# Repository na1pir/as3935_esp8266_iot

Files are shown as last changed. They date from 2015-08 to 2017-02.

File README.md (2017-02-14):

# Thunderstorm sensor protected iot switch
*Another a bit more complex project written in c with espressif sdk for my diploma thesis, so it is in prototype stage and work in progress when I have time to work on it . . .*

Copyright (c) 2015 Uroš Golob <golob.uros@gmail.com> 
 
Work was done with intention to protect electronic devices and so lower e-waste.
It might work or it may not, just don't sue me if your house burns down or if it kills you...

This software and hardware is described in my diploma thesis(work in progress). 
   
Use it for *personal* use as you wish, just keep this notice on it if you do! 
And return changes back free of charge by same restrictions and notice! 

This software uses espressif sdk software, spi library from David Ogilvy(MetalPhreak) and libesphttpd & wifi settins form Jeroen Domburg(sprite_fm). So use and rescpect their respective licencies for their work. 

Development took alot of time and money so remember me with some spare 
bitcoins: 1MaGphnuiMjywjQPKHKF239wzcef4KpNxX if you wish:)

For comercial use you can contact me and we can make some separate licencing deal...

## What it is?
Well this thing uses some crazy trickery from ams... and lovely soc from espressif... 
OK as3935 is (well not so simple) chip that uses LC antenna tuned to 500khz to detect lightning discharges.
It measures amplitude and uses some crazy statistics to determine distance from face of the thunderstorm. And gladly ignores man made discharges.
Well I added a bit of trickery of my own to libesphttpd and used spi driver to talk to as3935 with esp8266.
When you mix everything together add couple of passives, transistor, optotransistor and relays you got a switch that disengages relay when it detect nearby thunderstorm. 

This is my baby and so work in progress and maybe never ending rolling release... 

Well you can order boards from [DirtyPCB's] 
(http://dirtypcbs.com/view.php?share=10417&accesskey=882ad84b962361d538d1656b4bbab783)

## bom: 
 * esp-201 or esp12 or esp12e
 * as3935
 * ma5532
 * ams1117 3.3
 * optotransistors
 * npns
 * couple of R, C & D 
 * pair of relays

## how to:
1. get yourself working esp-open-sdk + newer sdk from espressif and link it to esp-open-sdk/sdk 
2. additionally get working sprite_fm libesphttpd and cats/led example so you can check and update any changes... 
3. find spi driver from MetalPhreak and check that example

 * I should add everything as git sub-modules, but as of now I don't know how...

 * make sure to export your esp-open-sdk/xtensa-lx106-elf/bin path to system path... additionally export esp-open-sdk/sdk as SDK_BASE, then ESPTOOL... in ubuntu it is best to do it in .profile  

4. from as3935_esp8266_iot folder run

	**make clean all**

5. put esp into boot mode (i have reset and boot(rst and gpio0 respectively to gnd) buttons soldered into my board) so press reset and boot then lift reset first then boot and run

	**make burn** 
or 
	**sudo make burn** 
if your dial-out permission thingy stuffs aren't setup properly

6. for debbuging

	**make tty**

7. setup geany for above commands it will save you lots of time

*todo: fix all issues*

## user interface looks like this: 
![settings web page]
(https://github.com/na1pir/as3935_esp8266_iot/raw/master/webpage.png)

Text for thesis is available at https://dk.um.si/Dokument.php?id=99783&lang=eng
It is in Slovene language but generaly you can still look at pictures.

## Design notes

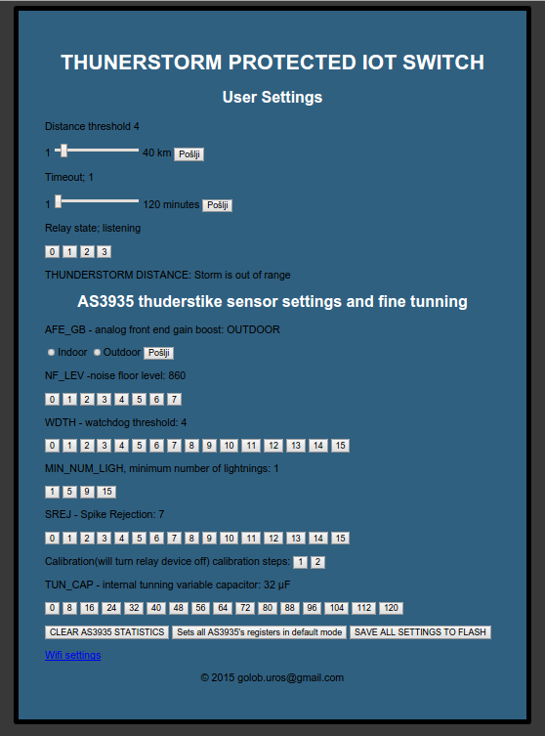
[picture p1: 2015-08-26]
webpage.png

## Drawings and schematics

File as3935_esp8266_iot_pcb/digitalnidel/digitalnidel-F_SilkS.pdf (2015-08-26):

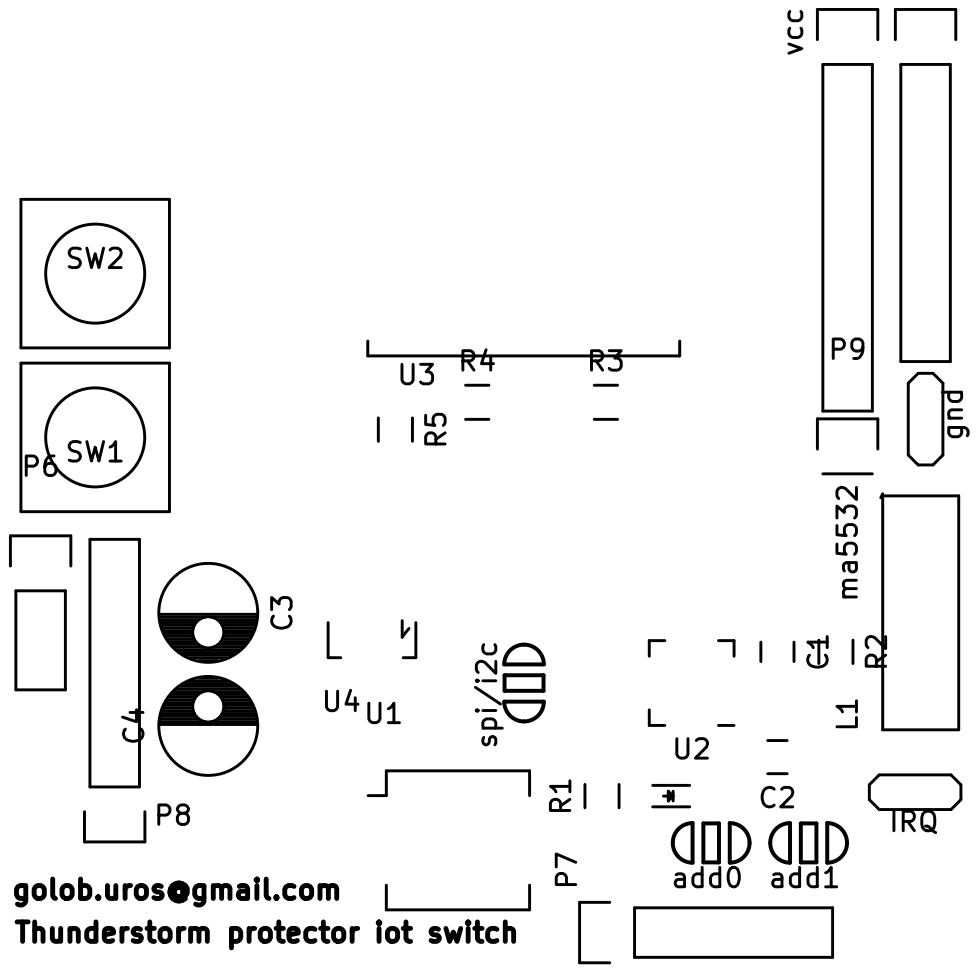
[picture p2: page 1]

Thunderstorm protector iot switch

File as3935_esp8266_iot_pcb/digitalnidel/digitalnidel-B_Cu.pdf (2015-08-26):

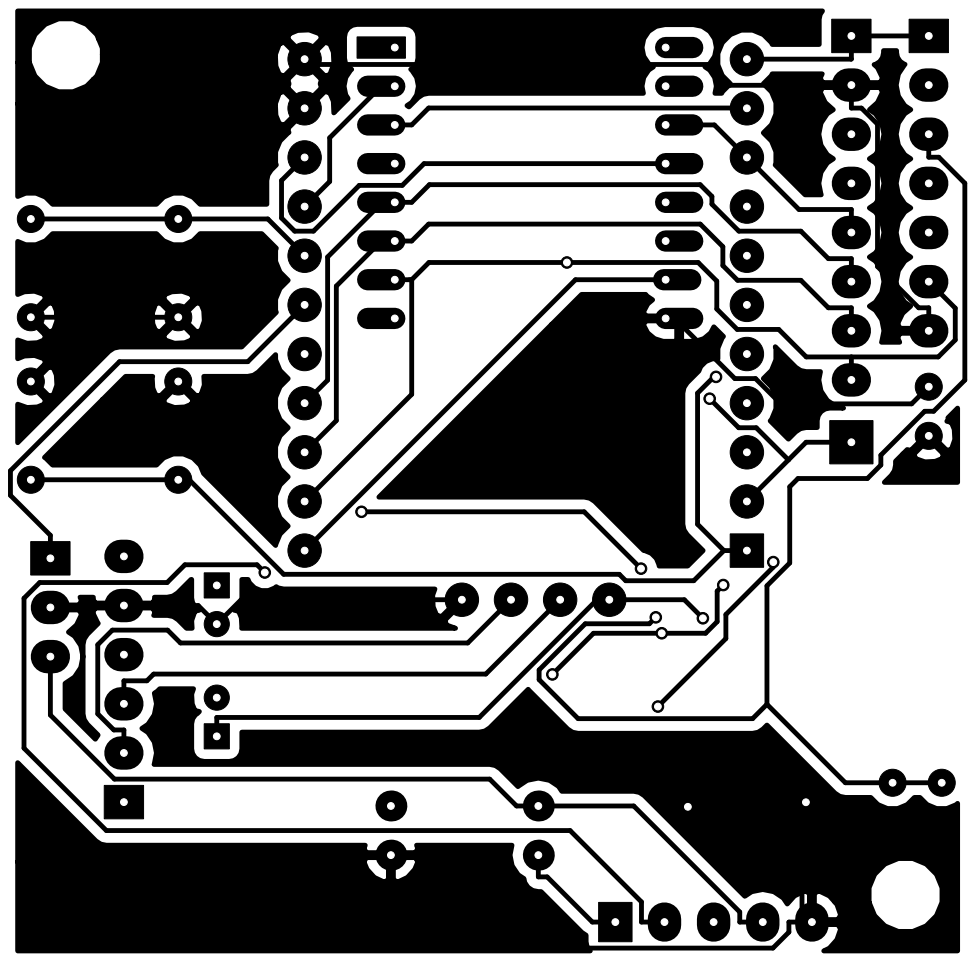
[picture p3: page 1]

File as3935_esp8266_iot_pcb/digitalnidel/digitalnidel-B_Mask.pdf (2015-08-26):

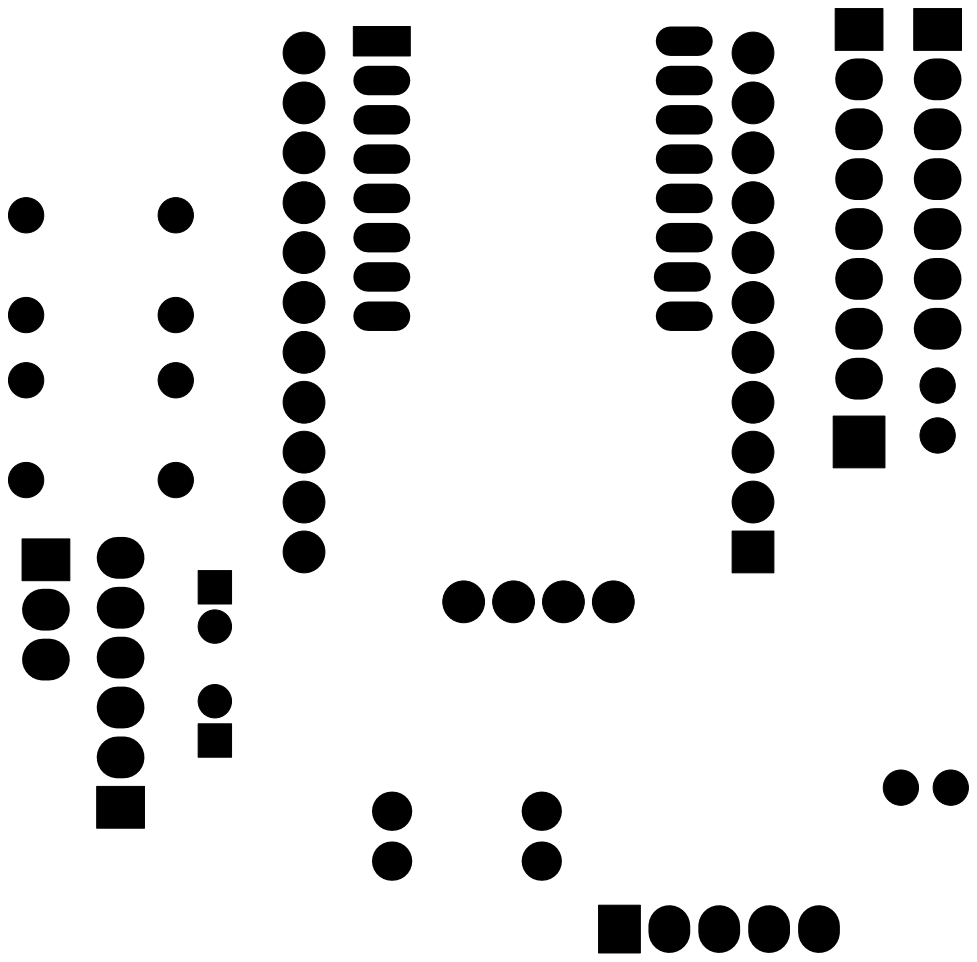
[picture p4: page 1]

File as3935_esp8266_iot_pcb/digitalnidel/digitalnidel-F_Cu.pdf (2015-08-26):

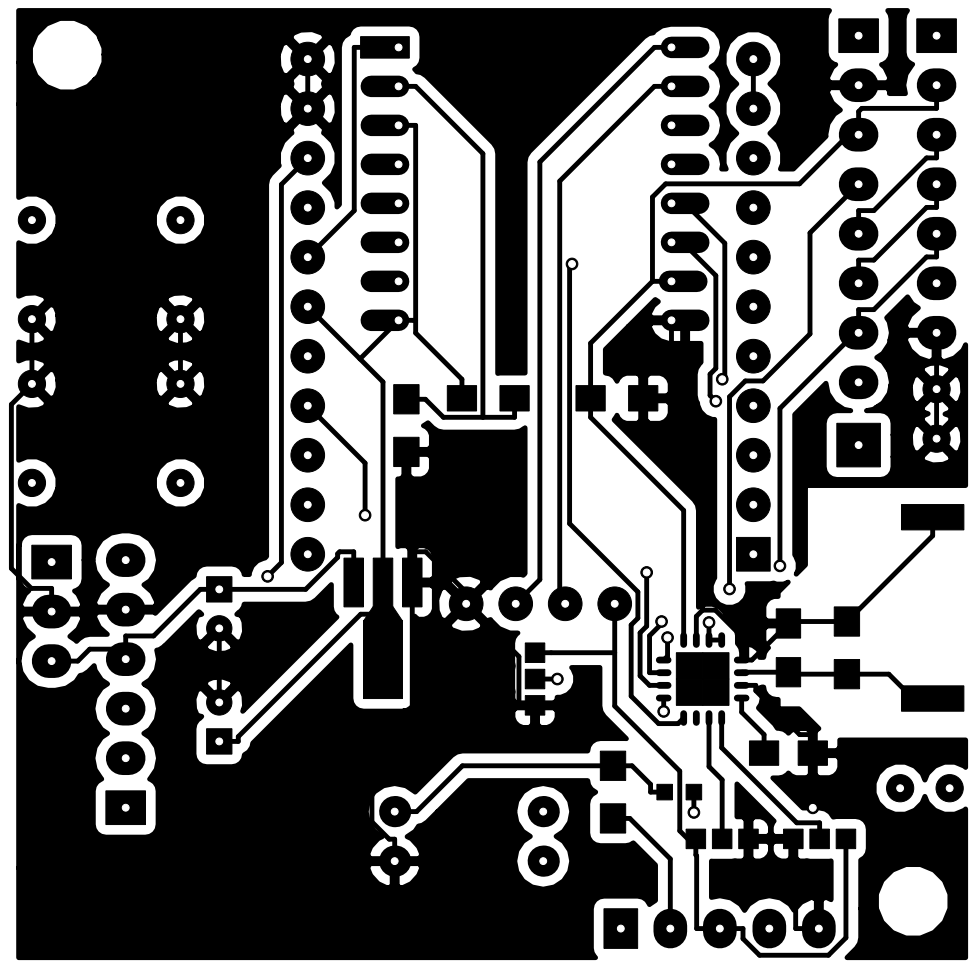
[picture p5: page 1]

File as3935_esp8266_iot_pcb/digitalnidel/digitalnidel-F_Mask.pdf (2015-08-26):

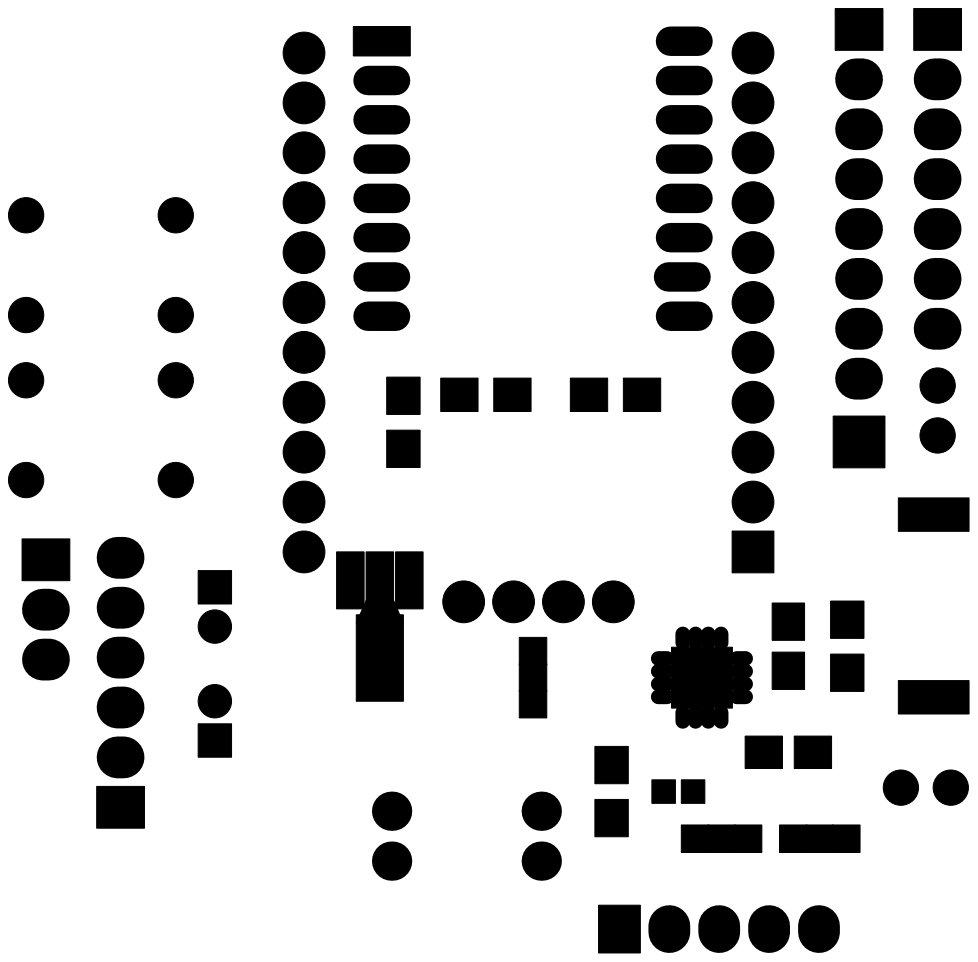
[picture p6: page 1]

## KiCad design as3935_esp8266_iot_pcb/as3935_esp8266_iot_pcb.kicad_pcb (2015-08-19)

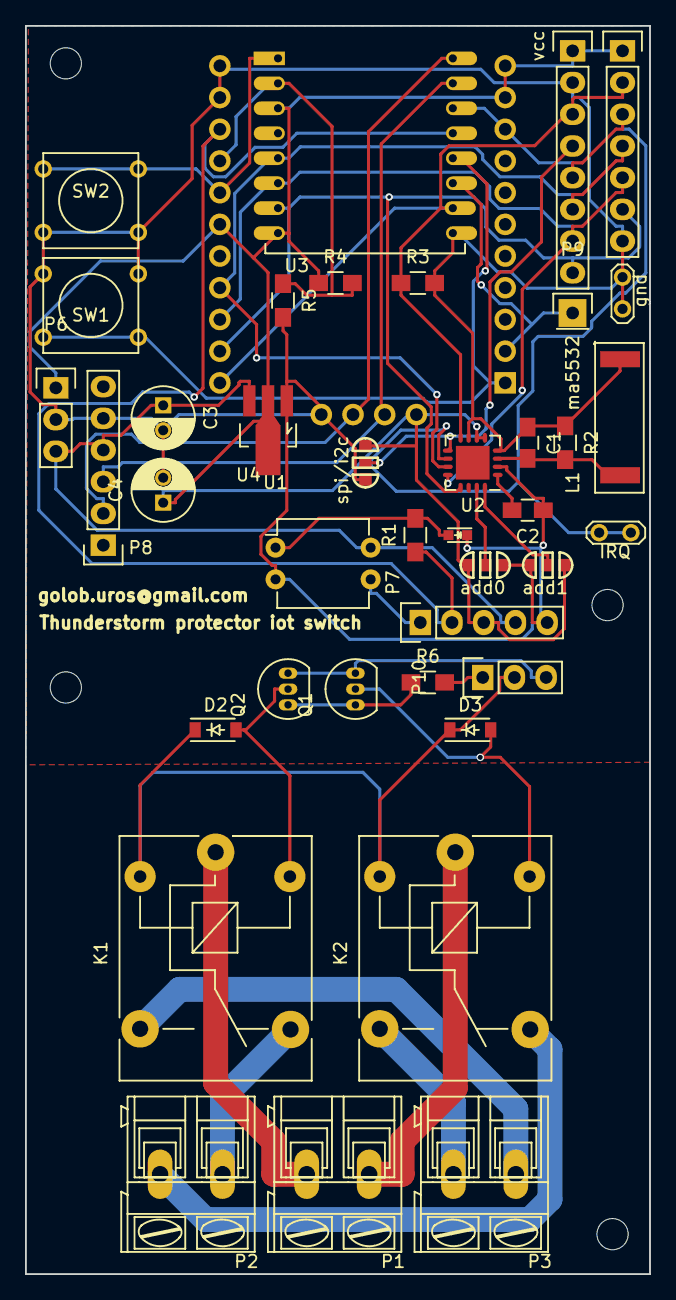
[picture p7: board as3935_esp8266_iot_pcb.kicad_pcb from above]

Board: 2 copper layers, 50.0 x 100.0 mm, 44 parts (0 on the bottom side), 31 nets.

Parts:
C1, C2: C; C_0805_HandSoldering
C3, C4: C; C_Radial_D5_L11_P2
D1: LED; LED-0603
D2, D3: D; SOD-123
IRQ: TEST; TESTPOINT
K1, K2: RELAY_2RT; relay
L1: ma5532
P1, P2, P3: CONN_01X02; AK300-2
P5: CONN_01X07; Pin_Header_Straight_1x07
P6, P10: CONN_01X03; Pin_Header_Straight_1x03
P7: CONN_01X05; Pin_Header_Straight_1x05
P8: CONN_01X06; Pin_Header_Straight_1x06
P9: CONN_01X01; Pin_Header_Straight_1x01
Q1, Q2: Q_NPN_BCE; TO-92_Inline_Narrow_Oval
R1, R2, R3, R4, R5, R6: R; R_0805_HandSoldering
REF1, REF2, REF3, REF4: MountingHole_2-5mm
SW1: SW_FLASH; SW_PUSH_SMALL
SW2: SW_RESET; SW_PUSH_SMALL
U1: PC817; DIP-4_W7.62mm
U2: as3935; UQFN-16-1EP_4x4mm_Pitch0.65mm
U3: ESP-12
U4: ESP-201
U5: AP1117D33; SOT89-3_Housing_Handsoldering
add0, add1: JUMPER3; sj3
gnd: TEST; TESTPOINT
spi/i2c: JUMPER3; sj3
vcc: CONN_01X08; Pin_Header_Straight_1x08

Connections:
+3V3: C4.1, P5.1, P6.1, P7.3, R4.1, U2.5, U2.6, U3.3, U3.8, U4.10, U4.11, U4.17, U4.26, U5.2, add0.1, add1.1, spi/i2c.1, vcc.1
+5V: C3.1, D2.1, D3.1, K1.8, K2.8, P6.3, P7.4, P8.4, P10.2, U1.4, U5.3
/adc: R4.2, R5.1, U3.2, U4.15
/add0: U2.15, add0.2
/add1: U2.16, add1.2
/clk: P5.4, U2.11, U3.5, U4.19, vcc.6
/cs: P5.2, R3.1, U2.8, U3.10, U4.22, vcc.3
/flash: SW1.1, U3.12, U4.1
/irq: IRQ.1, P5.3, U2.10, U3.14, U4.9, vcc.5
/miso: P5.5, U2.12, U3.6, U4.20, vcc.7
/mosi: P5.6, U2.13, U3.7, U4.21, vcc.8
/reset: SW2.1, U3.1, U4.16
/rx: P8.3, U3.15, U4.25
/si: U2.9, spi/i2c.2, vcc.4
/to_sw: P7.2, R1.1, U3.13, U4.14
/to_switch: P7.1, P10.1, R6.2, U1.3
/tx: P8.2, U3.16, U4.24
GND: C1.1, C2.1, C3.2, C4.2, D1.1, L1.1, P5.7, P6.2, P7.5, P8.5, P10.3, Q1.3, Q2.3, R2.1, R3.2, R5.2, SW1.2, SW2.2, U1.2, U2.2, U2.4, U2.7, U3.9, U4.12, U4.13, U4.23, U5.1, add0.3, add1.3, gnd.1, spi/i2c.3, vcc.2
unnamed: C1.2, L1.2, R2.2, U2.3
unnamed: C2.2, U2.1
unnamed: D1.2, R1.2, U1.1
unnamed: D2.2, K1.9, Q2.2
unnamed: D3.2, K2.9, Q1.2
unnamed: K1.1, P2.1
unnamed: K1.3, P3.1
unnamed: K1.5, P1.2
unnamed: K2.1, P2.2
unnamed: K2.3, P3.2
unnamed: K2.5, P1.1
unnamed: P9.1, U3.11, U4.2
unnamed: Q1.1, Q2.1, R6.1

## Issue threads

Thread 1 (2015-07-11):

TUN_CAP and WDTH

na1pir, 2015-07-11:
only even web gui buttons for adjusting cunning capacitors work.

na1pir, 2015-07-13:
Using different debug printouts I fined out that correct values get from esp8266 webpage to where we write that into as3935. So process of writing that into chip or read back is real issue.

na1pir, 2015-07-26:
same problem applies to WDTH as well

na1pir, 2015-08-11:
WRITE_PERI_REG(SPI_CTRL2(HSPI), 2<<SPI_MOSI_DELAY_MODE_S);
fixed wrong writing to chip so read-back became correct as well.
might need some additional testing thou ...

Closed 2015-08-11.

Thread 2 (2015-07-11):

lco calibration

na1pir, 2015-07-11:
lco calibration doesn't work there must be something wrong with spi protocol or maybe with delays.

na1pir, 2015-07-13:
fixed by adding additional reserved bit into as3935 structure

Closed 2015-07-13.

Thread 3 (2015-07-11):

interrupts won't fire

na1pir, 2015-07-11:
probably something wrong with gpio settings

na1pir, 2015-08-11:
currently just reading irq pin in procTask and functionality is almost as same as interrupts...

na1pir, 2016-03-20:
issue was hardware based

Closed 2016-03-20.

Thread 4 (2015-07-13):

interrupt noise and disturber log  on webpage

na1pir, 2015-07-13:
it would be nice if we would have printout for disturbers and noise level to high interrupts
and settings to disable disturbers

na1pir, 2015-08-11:
maybe current interrupt value would be good enough.

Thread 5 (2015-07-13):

saving settings to flash

na1pir, 2015-07-13:
it would be nice if we could save settings to flash;
-1 default settings button
-couple different profiles for different settings so if we use device in multiple locations.
-loading last used settings on boot

na1pir, 2015-07-30:
implemented partially - I guess all that we actually need:
- 1 save button for saving all settings
- loading that setting on boot time

Closed 2015-07-30.

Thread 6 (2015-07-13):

currently relay does not switch in listening mode

na1pir, 2015-07-13:
This is probably because of interrupts won't fire, so we are not switching between stages like software design intended (to switch between stages). So when we fix interrupts all should be well.
I should recheck all stages an maybe add intermediate stages better called pending.

na1pir, 2015-07-26:
after some tweaking we can do without interrupts only by pulling data from registers, but our response time is fixed to 1-2 seconds

Closed 2015-07-26.

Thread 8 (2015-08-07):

visual feedback - blinkenlights

na1pir, 2015-08-07:
you could add some sort of visual feedback for certain danger level and device state in form of blinkenlights :)

na1pir, 2015-08-12:
https://github.com/cnlohr/esp8266ws2812i2s would make sense for this, but then we lose uart line for debugging.

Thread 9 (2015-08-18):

auto update webpage for changes

na1pir, 2015-08-18:
you could use websockets for updating distance, last interrupts, current register values,...

na1pir, 2015-08-18:
you could even stream debug data instead of using uart

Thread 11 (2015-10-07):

pcb error

na1pir, 2015-10-07:
esp8266 can't drive inductive load directly, nor can it drive specified opto-transistor

na1pir, 2015-10-18:
well I guess fake esp12e modules are responsible for this one, because they mistakenly switched gpio5 and gpio4

na1pir, 2016-01-02:
not certain if I should change that since all boards I have save gpio 4 and 5 switched in respect to this pcb.

na1pir, 2016-03-20:
this is couse of #3

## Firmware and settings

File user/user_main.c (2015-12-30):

/*
 * Copyright (C) 2015 Uroš Golob <golob.uros@gmail.com>
 * 
 * Work was done with intention to protect electronic devices and so lower e-waste.
 * It might work or it may not, just don't sue me if your house burns down or if it kills you...
 * 
 * This software and hardware is described in my diploma thesis(work in progress). 
 *   
 * Use it for personal use as you wish, just keep this notice on it if you do! 
 * And return changes back free of charge by same restrictions and this notice! 
 * 
 * For comercial use you can contact me and we can make apropriate licencing deal...
 *
 * Development took alot of time and money so remember me with some spare 
 * bitcoins: 1MaGphnuiMjywjQPKHKF239wzcef4KpNxX if you wish:)
 * 
 * This software uses espressif sdk software, spi library from David Ogilvy(MetalPhreak) and libesphttpd & wifi settins from Jeroen Domburg(sprite_fm). So use and rescpect their respective licencies for their work. 
 */
 #include <stdint.h>
#include <esp8266.h>
#include "httpd.h"
#include "httpdespfs.h"
#include "cgi.h"
#include "cgiwifi.h"
#include "cgiflash.h"
#include "stdout.h"
#include "espfs.h"
#include "captdns.h"
#include "webpages-espfs.h"

#include "ets_sys.h"
#include "osapi.h"
#include "gpio.h"
#include "os_type.h"
#include "user_config.h"
#include "uart.h"
#include "uart_register.h"
#include "user_interface.h"
#include "ip_addr.h"
#include "espconn.h"
#include "as3935.h"
#include "spi_flash.h"
#include "mem.h"
#include "espconn.h"
#include "driver/spi.h"
#include "driver/spi_register.h"

uint32_t i;


volatile uint32_t in_detection_counter=0;

volatile uint8_t tick_flag = 1;
volatile uint8_t interrupt_flag=0;
volatile uint8_t interrupt_set=0;
volatile uint8_t tock=1;


void user_rf_pre_init(void){
	//just becouse we have to http://bbs.espressif.com/viewtopic.php?t=486&p=1895
//initialize things that should be done before rf connection - nothing actualy
}

//0 off
//1 on
//2 calibration
//3 listening
//4 in detection treshold > distance //relay on
//5 in detection treshold > distance timeout //relay off we are out of danger but timeout is still pending 
//6 in detection treshold < distance //off

volatile uint8_t state_machine=0;

 uint8_t threshold_distance=30;
 uint8_t threshold_timeout=15;

 uint8_t tuncaplookuptable[]={ 0,8,16,24,32,40 ,48 ,56 ,64 ,72,80,88,96,104,112,120};
 uint16_t noise_outdoor[]={390, 630, 860, 1100, 1140, 1570, 1800, 2000};
 uint16_t noise_indoor[]={28, 45, 62, 78, 95, 112, 130, 146};
 uint8_t min_num_ligh[]={1,5,9,15};
 uint8_t lcofdiv[]={16,32,64,128};


HttpdBuiltInUrl builtInUrls[]={
	{"/", cgiRedirect, "/index.tpl"},
	{"/index.tpl", cgiEspFsTemplate, tplas3935},
	{"/as3935.cgi", cgias3935, NULL},

	//Routines to make the /wifi URL and everything beneath it work.

	{"/wifi", cgiRedirect, "/wifi/wifi.tpl"},
	{"/wifi/", cgiRedirect, "/wifi/wifi.tpl"},
	{"/wifi/wifiscan.cgi", cgiWiFiScan, NULL},
	{"/wifi/wifi.tpl", cgiEspFsTemplate, tplWlan},
	{"/wifi/connect.cgi", cgiWiFiConnect, NULL},
	{"/wifi/connstatus.cgi", cgiWiFiConnStatus, NULL},
	{"/wifi/setmode.cgi", cgiWiFiSetMode, NULL},

	{"*", cgiEspFsHook, NULL}, //Catch-all cgi function for the filesystem
	{NULL, NULL, NULL}
};

uint64_t seconds_from_boot=0;

void ICACHE_FLASH_ATTR ticker_timer(void *arg)
{
	tick_flag=1;
	if(state_machine>4){//2
		in_detection_counter++;//this is reseted in solid state machine 6
	}
	seconds_from_boot++;
	//if(seconds_from_boot%15==0){
		os_printf("Heap: %ld\nAFE_GB[%d],NF_LEV[%d],WDTH[%d],MIN_NUM_LIGH[%d],SREJ[%d],INT[%d],LCO_FDIV[%d],MASK_DIST[%d],DISTANCE[%d],TUN_CAP[%d], STATE[%d]\n",(unsigned long)system_get_free_heap_size(),as3935.x0.a0.AFE_GB,as3935.x1.a1.NF_LEV,as3935.x1.a1.WDTH,as3935.x2.a2.MIN_NUM_LIGH,as3935.x2.a2.SREJ,as3935.x3.a3.INT,as3935.x3.a3.LCO_FDIV,as3935.x3.a3.MASK_DIST,as3935.x7.a7.DISTANCE,as3935.x8.a8.TUN_CAP,state_machine);
	//}
}



#define procTaskPrio        0
#define procTaskQueueLen    1

os_timer_t some_timer;
os_event_t    procTaskQueue[procTaskQueueLen];

//0 off
//1 on
//2 calibration
//3 listening
//4 in detection treshold > distance //relay on
//5 in detection treshold > distance timeout //relay off we are out of danger but timeout is still pending 
//6 in detection treshold < distance //off
static void ICACHE_FLASH_ATTR procTask(os_event_t *events)
{

	//reschedule
	system_os_post(procTaskPrio, 0, 0 );
	
	
	if(tick_flag==1){
		//todo if interrups start to work anytime soon you only read periodicly when in detection 
		if(tock==1){
			if(state_machine>2){
				as3935_chip_read();
			}
			tock=0;
		}
		else{//alternative to interrupts
		if(GPIO_INPUT_GET(GPIO_ID_PIN(INT_PIN))){//instead of interrupt just read
			pending_interrupt();
		}
			tock=1;
			if(state_machine>2){
				if(as3935.x7.a7.DISTANCE<threshold_distance){
					uart0_sendStr("atention:\n");
					state_machine=6;
				}
			}
				
		}

		tick_flag=0;
		if(interrupt_flag){
			clear_interrupt();
			interrupt_flag=0;
			//return;
		}
		
		if(state_machine==6){
			if(!interrupt_set){
				setup_interrupt();
			}
			as3935_get_lightning_distance();
			if(as3935.x7.a7.DISTANCE<threshold_distance){
				GPIO_OUTPUT_SET(GPIO_ID_PIN(RELAY_PIN),0);//off
				in_detection_counter=0; //reset counter
				uart0_sendStr("danger\n");
				//return;
			}else {
				state_machine=5;
				//return;
			}
		}
		
		if(state_machine==5){
			if(!interrupt_set){
				setup_interrupt();
			}
			if(in_detection_counter>threshold_timeout*60){
					state_machine=4;	
			}
			uart0_sendStr("awaiting timeout\n");
			//return;
		}
		
		if(state_machine==4){
			if(!interrupt_set){
				setup_interrupt();
			}
			GPIO_OUTPUT_SET(GPIO_ID_PIN(RELAY_PIN),1);	
			if(as3935.x7.a7.DISTANCE==63){
				state_machine=3;
				
				uart0_sendStr("thunderstorm passed\n");
				//return;
			}
		}

		if(state_machine==1){
			as3935_disable_LCO_calibration_mode();
			disable_interrupt();
			uart0_sendStr("on\n");
			GPIO_OUTPUT_SET(GPIO_ID_PIN(RELAY_PIN),1);	
		}
		
		if(state_machine==2){
			if(interrupt_set){
				disable_interrupt();
			}
			GPIO_OUTPUT_SET(GPIO_ID_PIN(RELAY_PIN),0);	
			uart0_sendStr("lco cal\n");
			as3935_enable_LCO_calibration_mode();
		}
		
		if(state_machine==0){
			as3935_disable_LCO_calibration_mode();
			if(interrupt_set){
				disable_interrupt();
			}
			uart0_sendStr("off\n");
			GPIO_OUTPUT_SET(GPIO_ID_PIN(RELAY_PIN),0);	
			//uart0_sendStr("off\n");
		}
		
		if(state_machine==3){
			as3935_disable_LCO_calibration_mode();
			if(!interrupt_set){
				setup_interrupt();
			}
			GPIO_OUTPUT_SET(GPIO_ID_PIN(RELAY_PIN),1);	
			uart0_sendStr("thunderstrike protection\n");
		}
	}//tok
}




#define SSID "wlan"
#define SSID_PASSWORD "password"


void user_init(void) {
	
	char ssid[32] = SSID;
    char password[64] = SSID_PASSWORD;
    struct station_config station_conf;
    
    //Set station mode (connecting to another network great for testing)
    //wifi_set_opmode( 0x1 );
    
    //or lets just make our own - for offline
   // wifi_set_opmode( 0x2 );
    
    //station+softap 
	wifi_set_opmode( 0x3 ); //warning power hungry

    //Set ap settings
    os_memcpy(&station_conf.ssid, ssid, 32);
    os_memcpy(&station_conf.password, password, 64);
    wifi_station_set_config(&station_conf);
	
	stdoutInit();

	//initialize chip
	as3935_init();
	
	//enable "clock" couter
	system_os_task(procTask, procTaskPrio, procTaskQueue, procTaskQueueLen);
	os_timer_disarm(&some_timer);
	os_timer_setfn(&some_timer, (os_timer_func_t *)ticker_timer, NULL);
	os_timer_arm(&some_timer, 1000, 1); 
	
	//sqedule worker task
	system_os_post(procTaskPrio, 0, 0 );

	// 0x40200000 is the base address for spi fash memory mapping, ESPFS_POS is the position
	// where image is written in flash that is defined in Makefile.
#ifdef ESPFS_POS
	espFsInit((void*)(0x40200000 + ESPFS_POS));
#else
	espFsInit((void*)(webpages_espfs_start));
#endif
	httpdInit(builtInUrls, 80);
	
	load_setings();

	os_printf("\nInit done!\n");
}

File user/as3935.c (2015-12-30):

/*
 * Copyright (C) 2015 Uroš Golob <golob.uros@gmail.com>
 * 
 * Work was done with intention to protect electronic devices and so lower e-waste.
 * It might work or it may not, just don't sue me if your house burns down or if it kills you...
 * 
 * This software and hardware is described in my diploma thesis(work in progress). 
 *   
 * Use it for personal use as you wish, just keep this notice on it if you do! 
 * And return changes back free of charge by same restrictions and this notice! 
 * 
 * For comercial use you can contact me and we can make apropriate licencing deal...
 *
 * Development took alot of time and money so remember me with some spare 
 * bitcoins: 1MaGphnuiMjywjQPKHKF239wzcef4KpNxX if you wish:)
 * 
 * This software uses espressif sdk software, spi library from David Ogilvy(MetalPhreak) and libesphttpd & wifi settins from Jeroen Domburg(sprite_fm). So use and rescpect their respective licencies for their work. 
 */

#include "as3935.h"

struct as3935_t as3935;

void pending_interrupt(){
	uart0_sendStr("interrupt\n");
		interrupt_flag=1;
}


void ICACHE_FLASH_ATTR clear_interrupt(){
	//clear interrupt status
	
	if(state_machine<3)return;
	uart0_sendStr("clear irq\n");
	GPIO_REG_WRITE(GPIO_STATUS_W1TC_ADDRESS, GPIO_REG_READ(GPIO_STATUS_ADDRESS) );
	
	as3935_chip_read();
	switch(as3935.x3.a3.INT){
		case IRQ_L:
			uart0_sendStr("as3935 lightning event \r\n");
			//check if we are within treshold
			if(threshold_distance>as3935.x7.a7.DISTANCE){
				//switch relay off
				
				//GPIO_OUTPUT_SET(GPIO_ID_PIN(RELAY_PIN),0);
				//sqedule further checking
				if(state_machine>2)
					state_machine=6;
			}
			
		break;
		case IRQ_D:
			uart0_sendStr("as3935 disturber detected \r\n");
			
		break;
		case IRQ_NF:
			uart0_sendStr("as3935 noise lewel to high \r\n");
			//todo: print to web page that we need to change  settings
		break;
	}
}


void ICACHE_FLASH_ATTR setup_interrupt(){
	uart0_sendStr("setup interrupt\n");
	//disable interrupt if it is enabled
	ETS_GPIO_INTR_DISABLE();
	//setup a interrupt pin for possitive edge front trigger
	gpio_pin_intr_state_set(GPIO_ID_PIN(INT_PIN),GPIO_PIN_INTR_POSEDGE);//or GPIO_PIN_INTR_POSEDGE or GPIO_PIN_INTR_HILEVEL
	
	//set callback when interrupt trigeres 
	ETS_GPIO_INTR_ATTACH(pending_interrupt, 0);
	interrupt_set=1;
	
}

void ICACHE_FLASH_ATTR disable_interrupt(){
	if(interrupt_set){
		uart0_sendStr("disable interrupt\n");
		//disable interrupt if it is enabled
		ETS_GPIO_INTR_DISABLE();

		interrupt_set=0;
	}
}

void  ICACHE_FLASH_ATTR as3935_chip_read(){
	uint8_t tm[100];
	int chip;
	
	HSPI_INIT_STUF;
	
	for(chip=0;chip<9;chip++){
//		system_soft_wdt_feed();
		switch(chip){
			case 0:
				as3935.x0.d0 = spi_read(chip);
			break;
			case 1:
				as3935.x1.d1 = spi_read(chip);
			break;
			case 2:
				as3935.x2.d2 = spi_read(chip);
			break;
			case 3:
				as3935.x3.d3 = spi_read(chip);
			break;
			case 4:
				as3935.x4.d4 = spi_read(chip);
			break;
			case 5:
				as3935.x5.d5 = spi_read(chip);
			break;
			case 6:
				as3935.x6.d6 = spi_read(chip);
			break;
			case 7:
				as3935.x7.d7 = spi_read(chip);
			break;
			case 8:
				as3935.x8.d8 = spi_read(chip);
			break;
		}
	}
/*		uint8_t tmp[1000];
os_sprintf(tmp,"[AFE_GB %d],[NF_LEV %d],[WDTH %d],[MIN_NUM_LIGH %d],[SREJ %d],[INT %d],[LCO_FDIV %d],[MASK_DIST %d],[DISTANCE %d],[TUN_CAP %d]\n",as3935.x0.a0.AFE_GB,as3935.x1.a1.NF_LEV,as3935.x1.a1.WDTH,as3935.x2.a2.MIN_NUM_LIGH,as3935.x2.a2.SREJ,as3935.x3.a3.INT,as3935.x3.a3.LCO_FDIV,as3935.x3.a3.MASK_DIST,as3935.x7.a7.DISTANCE,as3935.x8.a8.TUN_CAP);
			uart0_sendStr(tmp);*/
			uart0_sendStr(".");
}


//direct command
uint8_t ICACHE_FLASH_ATTR  as3935_dc(uint8_t dc){
	HSPI_INIT_STUF;
	spi_write(0x3d,0x96);
}

uint32_t ICACHE_FLASH_ATTR as3935_get_lightning_energy(){
	HSPI_INIT_STUF;
	as3935.x6.a6.S_LIG_MM=0;
	as3935.x5.a5.S_LIG_M=0;
	as3935.x4.a4.S_LIG_L=0;
	as3935.x4.d4=spi_read(4);	
	as3935.x5.d5=spi_read(5);
	as3935.x6.d6=spi_read(6);
	return ((uint32_t)as3935.x6.a6.S_LIG_MM<<16)+((uint32_t)as3935.x5.a5.S_LIG_M<<8)+(uint32_t)as3935.x4.a4.S_LIG_L;
}

//0b111111 means that it is out of range for calculation
//otherwise it is value in km
uint8_t ICACHE_FLASH_ATTR as3935_get_lightning_distance(){
	HSPI_INIT_STUF;
	as3935.x7.a7.DISTANCE=0;
	as3935.x7.d7=spi_read(7);
	return as3935.x7.a7.DISTANCE;
}

//returns:
// 1 for INT_NH noise level to high
// 4 for INT_D disturber detected 
// 8 for INT_L lightning detected
uint8_t ICACHE_FLASH_ATTR as3935_interrupt_source(){//get interrupt source but first wait for 2ms for chip to calculate what trigerred it
	system_soft_wdt_stop();
	HSPI_INIT_STUF;
	//this won't work
	os_delay_us(3000);
	as3935.x3.a3.INT=0;
	as3935.x3.d3=spi_read(3);
	system_soft_wdt_restart();
	return as3935.x3.a3.INT;
}

void ICACHE_FLASH_ATTR as3935_clear_stat(){
	HSPI_INIT_STUF;
	//REG0x02[6] 1->0->1
	spi_read(2);
	as3935.x2.a2.CL_STAT=1;
	spi_write(2,as3935.x2.d2);
	as3935.x2.a2.CL_STAT=0;
	spi_write(2,as3935.x2.d2);
	as3935.x2.a2.CL_STAT=1;
	spi_write(2,as3935.x2.d2);
}

//if we get interrupt for disturber  (IRQ_NOISE_FLOOR 0001)increes for 1, def:010, min:000, max:111

//returns values from 0 to 7 
uint8_t ICACHE_FLASH_ATTR as3935_get_noise_floor_level(){
	HSPI_INIT_STUF;
	as3935.x1.a1.NF_LEV=0;
	spi_read(1);
	return as3935.x1.a1.NF_LEV;
} 

//values from 0 to 7 are aceptable
void ICACHE_FLASH_ATTR as3935_set_noise_floor_level(uint8_t noise){
	HSPI_INIT_STUF;
	as3935.x1.a1.NF_LEV=noise;
	spi_write(1,as3935.x1.d1);
}
	
//before we acknolage thunderstorm
uint8_t ICACHE_FLASH_ATTR as3935_get_min_lightning_events(){
	HSPI_INIT_STUF;
	as3935.x2.a2.MIN_NUM_LIGH=0;
	spi_read(2);
	return as3935.x2.a2.MIN_NUM_LIGH;
} 


//value in register-> 	interpretation of minimal lightning  events before chip decides thet there is storm nearby
//REG0x02[5] REG0x02[4] 0->1,1->5,2->9,3->16
void ICACHE_FLASH_ATTR as3935_set_min_lightning_events(uint8_t num){
	HSPI_INIT_STUF;
	as3935.x2.a2.MIN_NUM_LIGH=num;
	spi_write(2,as3935.x2.d2);
}

//look if reporting of disturbers on interrupt pin is enabled
unsigned char ICACHE_FLASH_ATTR as3935_get_mask_disturbers(){
	HSPI_INIT_STUF;
	as3935.x3.a3.MASK_DIST=0;
	spi_read(3);
	return as3935.x3.a3.MASK_DIST;
}

//enable or disable reporting of disturbers 
//should be on only at setup and trublesuting
void ICACHE_FLASH_ATTR as3935_set_mask_disturbers(uint8_t enabled){
	HSPI_INIT_STUF;
	as3935.x3.d3=spi_read(3);
	as3935.x3.a3.MASK_DIST=enabled;
	spi_write(3,as3935.x3.d3);
}

//#define INDOOR 0b10010
//#define OUTDOOR 0b01110
//indoor == 0b10010 or outdoor == 0b01110
uint8_t ICACHE_FLASH_ATTR as3935_get_AFE_gainboost(){
	HSPI_INIT_STUF;
	as3935.x0.a0.AFE_GB=0;
	spi_read(0);
	return as3935.x0.a0.AFE_GB;
}

//#define INDOOR 0b10010
//#define OUTDOOR 0b01110
//indoor == 0b10010 or outdoor == 0b01110
void ICACHE_FLASH_ATTR as3935_set_AFE_gainboost(uint8_t gain){
	HSPI_INIT_STUF;
	as3935.x0.d0=spi_read(0);
	as3935.x0.a0.AFE_GB=gain;
	spi_write(0,as3935.x0.d0);
}
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

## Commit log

2015-07-06 initial commit it works a bit i guess but waiting for storm to test it... todo: distance probably not corect in this version find a flaw and fix it!!! todo: check if calibration actualy outputs anyth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
    [as3935.c]
2015-07-07 bunch of changes but still doesn't work todo: -irq won't fire -spi is still no go
    [as3935.c, cgi.c, user_main.c]
2015-07-09 alternative to interrupts
2015-07-11 changing spi clock based on http://www.esp8266.com/viewtopic.php?f=13&t=2367
2015-07-11 BIG RED FAIL BUTTON;"Whaaaaak whaaaak wahaak whak!" why oh why didn't i try that before as3935 structure registers were back to front, now everithing shuld be better:)
2015-07-11 there is something wrong with tun_cap
    [cgi.c, user_main.c]
2015-07-12 bug in as3935 structure(now we have functional calibration mode) todo: tuncap unable to set odd numbers interrupts won't fire
    [as3935.c, cgi.c]
2015-07-13 noise floor is calculated based on setting of noise floor and AFE and shown in μVrms
    [as3935.c, cgi.c, user_main.c]
2015-07-26 adding couple of pictures and few small changes in code so everithing works withouth interrupts
2015-07-28 only smal spelling mistake
    [as3935.c]
2015-07-30 added reset to defoult for as3935
    [cgi.c]
2015-08-11 possible fix for spi communication needs some more testing but i think that it works:)
    [as3935.c, spi.h, user_main.c]
2015-08-12 first pcb rototype it can carry esp-201 or esp-12, as3935 chip with ma5532-ae coil antenna or module mop-1016 from www.embeddedadventures.com or as3935 lightning sensor module from playingwithfusion.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
    [as3935_esp8266_iot_pcb.dsn, as3935_esp8266_iot_pcb.kicad_pcb, as3935_esp8266_iot_pcb.sch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]
2015-08-12 just simbols
    [as3935_esp8266_iot_pcb.kicad_pcb]
2015-08-12 copper fill
    [as3935_esp8266_iot_pcb.dsn, as3935_esp8266_iot_pcb.kicad_pcb, as3935_esp8266_iot_pcb.sch]
2015-08-12 copper fill, smd transistor, resistors and capacitors on universal pads for smd 805 or trough hole
    [as3935_esp8266_iot_pcb.kicad_pcb, as3935_esp8266_iot_pcb.sch]
2015-08-18 new layout, added second transistor for relay,... digital side of pcb cal drive any relay board from ebay or something
    [as3935_esp8266_iot_pcb.dsn, as3935_esp8266_iot_pcb.kicad_pcb, as3935_esp8266_iot_pcb.sch]
2015-08-19 small redesign
    [as3935_esp8266_iot_pcb.dsn, as3935_esp8266_iot_pcb.kicad_pcb, as3935_esp8266_iot_pcb.sch]
2015-08-26 added simple pcb containing only digital part with sensor and microcontroler module with embedded wifi you'll have to add your own relays
    [digitalnidel-B_Cu.gbr, digitalnidel-B_Mask.gbr, digitalnidel-B_SilkS.gbr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]
2015-09-05 couple quirks
2015-09-12 well actualy that should have been pico farads not micro farads ups my bad...
2015-12-30 small printf
